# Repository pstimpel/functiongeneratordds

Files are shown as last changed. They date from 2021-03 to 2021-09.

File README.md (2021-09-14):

# A function generator based in DDS, the AD9833

IMAGE ALT TEXT HERE (https://www.youtube.com/watch?v=zaaheF0XjLw)

## Core features

- +/- 10V 
- linear power supply, builtin
- Sweep function
- Random function
- Update OTA feature
- MQTT status and settings

## Credits

The whole stuff is based on the work by Youtuber GreatScott, whos instructions you can find here: https://www.instructables.com/DIY-FunctionWaveform-Generator/

Voice in Video by https://www.text2speech.org/

## BOM
### power circuit

- Transformer 230V to 2x 15V
- 4 diodes 1n4007
- 2 2200uF caps, 35V
- 2 330uF caps, 35V
- C14 socket with fuse and switch
- some wires to connect C14 with transformer
- perfboard to mount the power circuit onto

### logic curciut

- 10u Capacitor
- 0.33u Capacitor
- 0.33u Capacitor
- 2.2u Capacitor
- 22u Capacitor
- 0.1u Capacitor
- 0.1u Capacitor
- 1u Capacitor
- 4x 100n Capacitor_SMD:C_0805
- LED 5mm
- Fuse 2A PTC
- 3x Screw Terminal Block
- GY9833 / AD9833 breakout board 3.3V
- 270 Ohms Resistor SMD: 0805
- 2x 100 Ohms Resistor THT 0.25W 5% or better
- 8-pin IC socket
- TL072 OpAmp
- 10k Trim Poti
- 10k Poti
- 50k Poti 
- AMS1117-3.3
- L7805
- L7812
- L7912
- ESP32 30 pin devboard
- Rotary Encoder
- OLED 0.96" display
- pinheaders male and female, dupont wires, stuff to wire power circuit and logic circuit together
- optional: MCP100-300D Voltage supervisor

### Case

- printed STLs from folder
- 10 screws M3x20 or similar
- 3 screws M3x12 or similar
- 1 screw M3x16 or similar
- 4 screws M4x20 or similar, 4 nuts of the same size

## How to build the case

Mount Back, bottom, front and topA to left, using M3x20 screws. Mount topB to topA by using M3x20 screws. Mount right to this whole assembly using M3x20 screws. Basically, this is the case for our Function Generator.

The lever is held to the front by an M3x16 screw, and secures the OLED.

## Logic PCB

I was creating a single sided PCB, so everyone with equipment should be able to create the PCB as well. However, I do not recommend using my board design. I had some parts laying around, and was recycling them by mixing SMD and THT with no bad feelings. 

## Improvements

2021-09-14 

- Added missing OpAmp
- replaced TL071 by TL072 for output buffering
- added 2 100 Ohms resistors in parallel to output for 50 Ohms Output
- added updated circuit and gerber stuff to repo 

## License

https://creativecommons.org/licenses/by-nc-sa/4.0/

Most obvious limits of this license:

- You are not allowed to use this stuff for commercial purposes
- You can download, reupload and change the stuff, but have to release it under the same license again
- You have the mention the origin, like "Original by Peter Stimpel, https://github.com/pstimpel/functiongeneratordds"

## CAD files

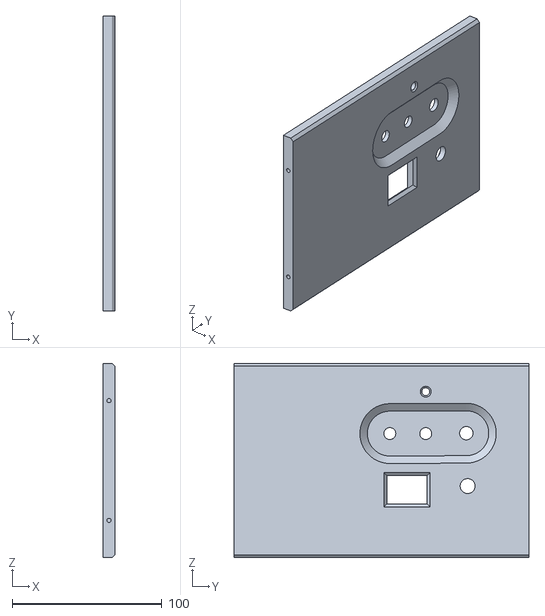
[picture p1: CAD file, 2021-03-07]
stl/front.stl
8.00 x 197.2 x 130.0

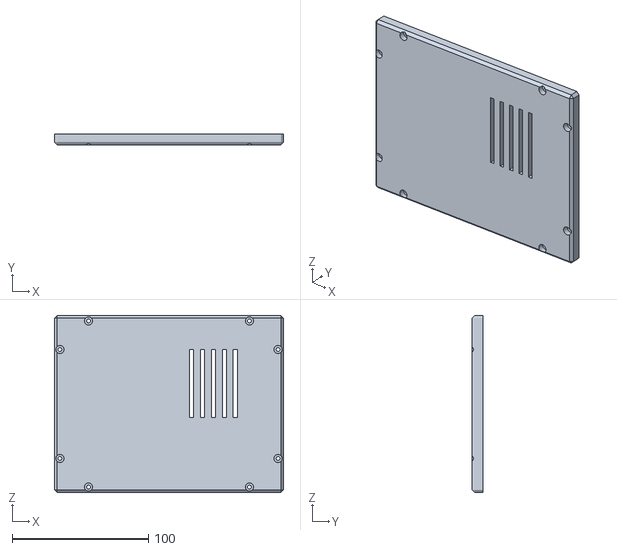
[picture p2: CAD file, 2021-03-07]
stl/left.stl
168.2 x 8.00 x 130.0

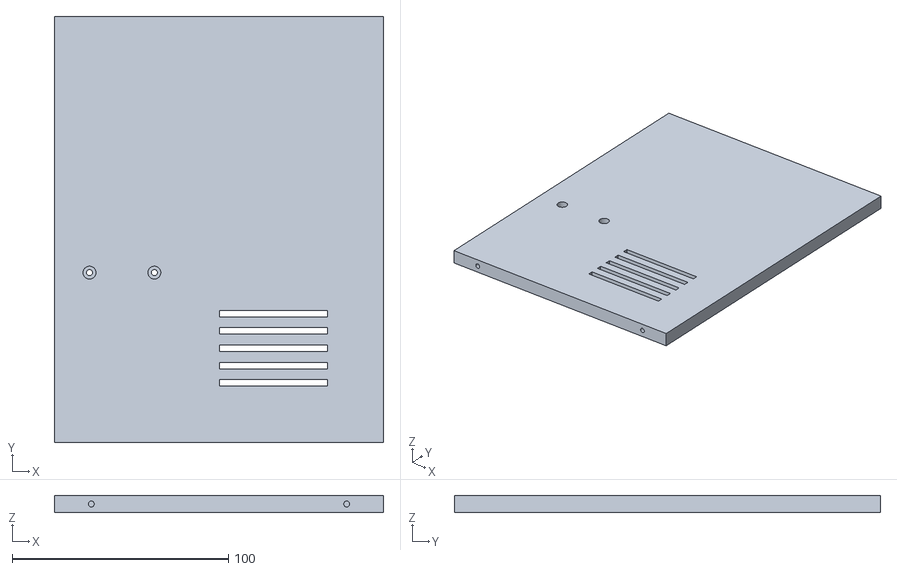
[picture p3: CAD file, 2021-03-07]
stl/topa.stl
152.2 x 197.2 x 8.00

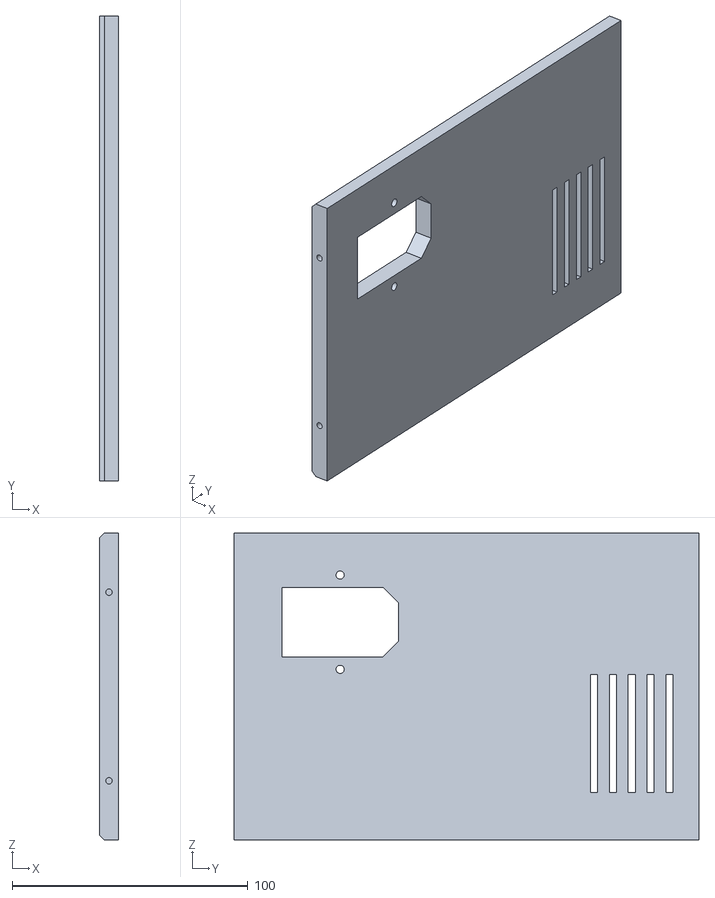
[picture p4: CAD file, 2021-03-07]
stl/back.stl
8.00 x 197.2 x 130.0

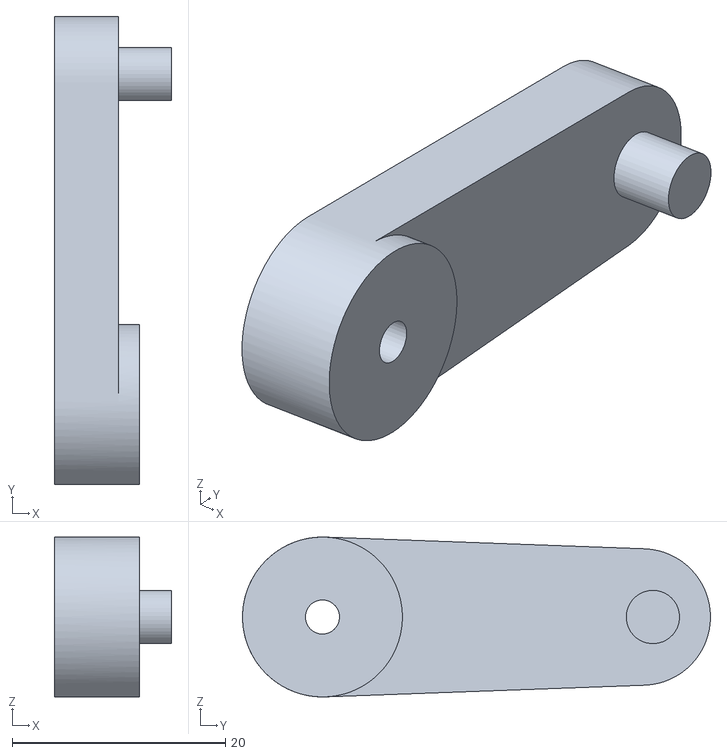
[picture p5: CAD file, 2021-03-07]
stl/lever.stl
11.0 x 43.9 x 15.0

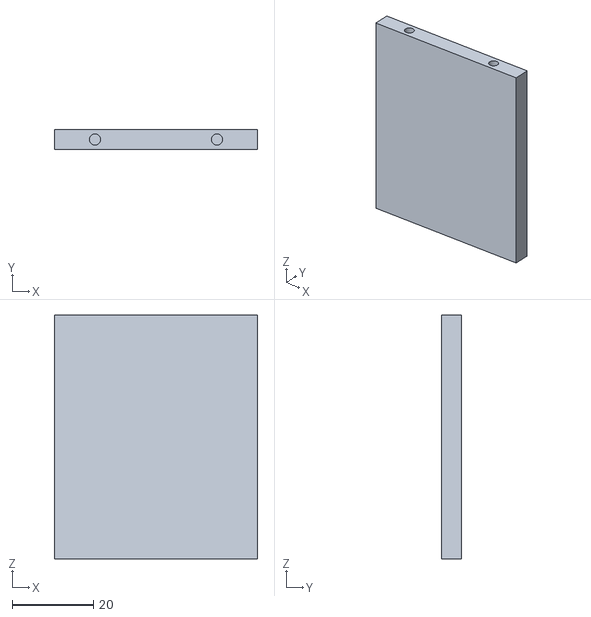
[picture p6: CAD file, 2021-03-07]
stl/topb.stl
50.0 x 5.00 x 60.0

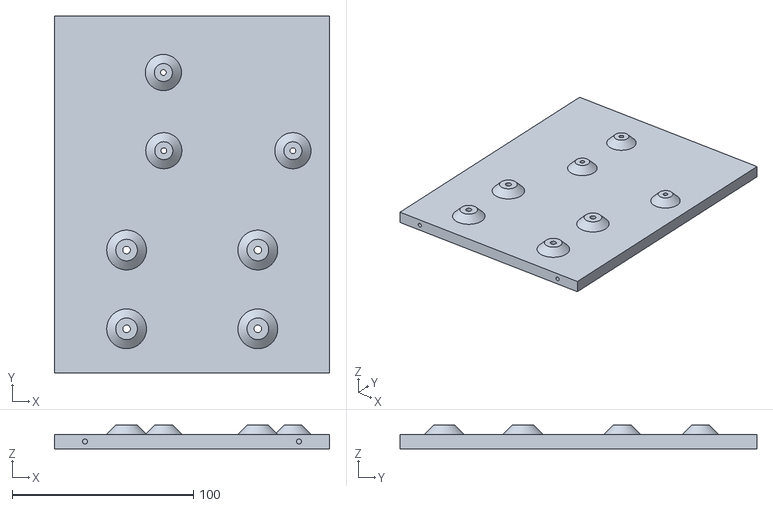
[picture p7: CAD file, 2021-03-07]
stl/bottom.stl
152.2 x 197.2 x 13.0

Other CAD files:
stl/right.stl

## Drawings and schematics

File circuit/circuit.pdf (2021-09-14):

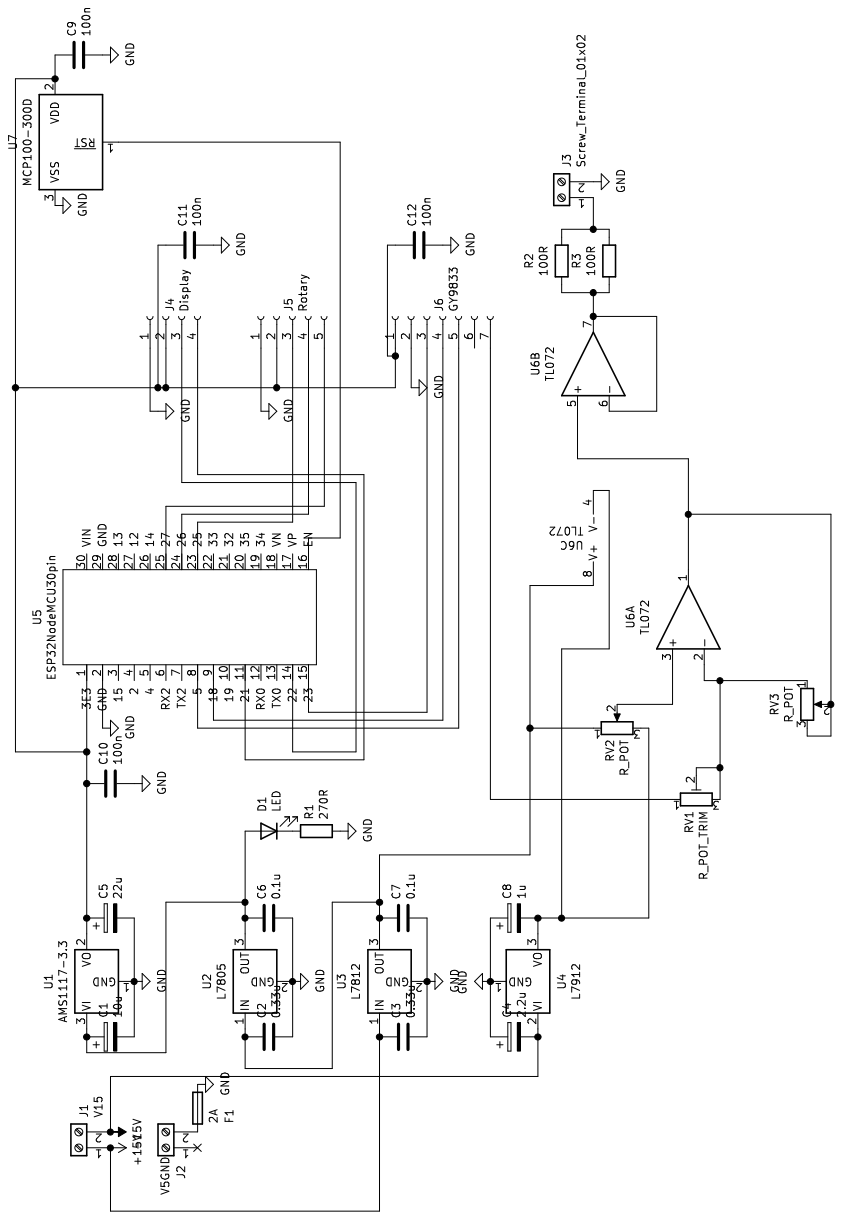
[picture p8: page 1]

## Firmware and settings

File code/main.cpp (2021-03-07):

#include <Arduino.h>
#include <MD_AD9833.h>
#include <SPI.h>
#include <ESP32Encoder.h>
#include <U8g2lib.h>
#include <Wire.h>
#include <WiFi.h>
#include <esp_wifi.h>
#include <PubSubClient.h>
#include <ArduinoJson.h>
#include <ESPmDNS.h>
#include <WiFiUdp.h>
#include <ArduinoOTA.h>
#include "time.h"

const char *versioninfo = "1.0.0-ota-1";

#define MQTT_VERSION MQTT_VERSION_3_1_1

#define DATA 23 ///< SPI Data pin number
#define CLK 18	///< SPI Clock pin number
#define FSYNC 5 ///< SPI Load pin number (FSYNC in AD9833 usage)

#define OLED_ADDR 0x3c
#define OLED_SDA 21
#define OLED_SCL 22
#define OLED_RST 16

#define ROTARY_ENCODER_A_PIN 27
#define ROTARY_ENCODER_B_PIN 26
#define ROTARY_ENCODER_BUTTON_PIN 25

#define uS_TO_S_FACTOR 1000000 /* Conversion factor for micro seconds to seconds */
#define TIME_TO_SLEEP 5        /* Time ESP32 will go to sleep (in seconds) */


U8G2_SSD1306_128X64_NONAME_F_HW_I2C u8g2(U8G2_R0, /* reset=*/OLED_RST, /* clock=*/OLED_SCL, /* data=*/OLED_SDA); // ESP32 Thing, HW I2C with pin remapping

//MD_AD9833 AD(FSYNC); // Hardware SPI
MD_AD9833 AD(DATA, CLK, FSYNC);
ESP32Encoder encoder;

volatile bool isclicked = false;
volatile boolean button = false;

const char *sensorname = "functiongeneratordds";

const char mqtt_switch_topic_command[] = "home/sensor/functiongeneratordds/out/switch";
const char mqtt_status_topic_status[] = "home/sensor/functiongeneratordds/status";
const char mqtt_SETTINGS_topic_status[] = "home/sensor/functiongeneratordds/settings";

const PROGMEM char *MQTT_CLIENT_ID = "functiongeneratordds__s";
const PROGMEM uint16_t MQTT_SERVER_PORT = 1883;
const PROGMEM char *MQTT_SENSOR_TOPIC = "home/sensor/functiongeneratordds/test";
const char *ssid = "YOURNETWORKNAME";
const char *password = "YOURPASSWORD";
const char *mqtt_server = "YOUR MQTT SERVERS IP ADDRESS";

const char* ntpServer = "pool.ntp.org";
const long  gmtOffset_sec = 0;
const int   daylightOffset_sec = 0;

const float frqUpper = 100000.0;
const float frqLower = 0.1;

float frqSingle = 1000.0;
float frqSweepLower = 1000.0;
float frqSweepUpper = 10000.0;
float sweepfrequencystep = 0.0;
float frq = frqSingle;

int duration = 5;
const int durationUpper = 3600;
const int durationLower = 1;

unsigned long encoder2lastToggled;
bool encoder2Paused = false;

volatile long oldencodervalue = 0;
bool encoderup = true;
long lastturndtected = millis();

int activeMain0 = 1;
int activeSingle1 = 1;
int activeSweep2 = 1;
int activeRandom3 = 1;
int frequencySelectedIndex = 0;
int activeScreen = 1;
char frequencychars[10];
int frequencycharsIndex = 0;
int frequencyScreenParentScreen = 0;
char integerchars[10];
int integercharsIndex = 0;
int integerSelectedIndex = 0;

bool doSingle = false;
bool doSweep = false;
bool doRandom = false;

volatile int errorcount=0;

WiFiClient wifiClient;
PubSubClient client(wifiClient);
MD_AD9833::mode_t desiredWaveform = MD_AD9833::MODE_SINE;

String charLocalTime()
{
    struct tm timeinfo;
    if(!getLocalTime(&timeinfo))
    {
    //Serial.println("Failed to obtain time");
    return "1970-01-01 00:00:00";
    }
    char timeStringBuff[50]; //50 chars should be enough
    strftime(timeStringBuff, sizeof(timeStringBuff), "%Y-%m-%dT%H:%M:%SZ", &timeinfo);
    //print like "const char*"
    return (String)timeStringBuff;
}

void print_wakeup_reason()
{
    esp_sleep_wakeup_cause_t wakeup_reason;

    wakeup_reason = esp_sleep_get_wakeup_cause();

    switch (wakeup_reason)
    {
    case ESP_SLEEP_WAKEUP_EXT0:
        Serial.println("Wakeup caused by external signal using RTC_IO");
        break;
    case ESP_SLEEP_WAKEUP_EXT1:
        Serial.println("Wakeup caused by external signal using RTC_CNTL");
        break;
    case ESP_SLEEP_WAKEUP_TIMER:
        Serial.println("Wakeup caused by timer");
        break;
    case ESP_SLEEP_WAKEUP_TOUCHPAD:
        Serial.println("Wakeup caused by touchpad");
        break;
    case ESP_SLEEP_WAKEUP_ULP:
        Serial.println("Wakeup caused by ULP program");
        break;
    default:
        Serial.printf("Wakeup was not caused by deep sleep: %d\n", wakeup_reason);
        break;
    }
}

void rebootBySleep() {
    esp_sleep_enable_timer_wakeup(TIME_TO_SLEEP * uS_TO_S_FACTOR);
    esp_deep_sleep_start();
}

void callback(char *topic, byte *message, unsigned int length)
{
    Serial.print("Message arrived on topic: ");
    Serial.print(topic);
    Serial.print(". Message: ");
    String messageTemp;

    for (int i = 0; i < length; i++)
    {
        Serial.print((char)message[i]);
        messageTemp += (char)message[i];
    }
    Serial.println();

    // Feel free to add more if statements to control more GPIOs with MQTT

    // If a message is received on the topic esp32/output, you check if the message is either "on" or "off".
    // Changes the output state according to the message
    if (String(topic) == String(mqtt_switch_topic_command))
    {
        Serial.print("Changing switch to ");
        if (messageTemp == "reset")
        {
            Serial.println(messageTemp);
            //do reset by going to deep sleep for 5 secs
            //syslog.logf(LOG_INFO, "Reset will be executed now");
            delayMicroseconds(2000000);
            rebootBySleep();
        }
        
    }
    
}

void reconnect()
{
    while (!client.connected())
    {
        //Serial.print("Attempting MQTT connection...");
        // Attempt to connect
        if (client.connect(sensorname))
        {

            //Serial.println("connected");
            // Subscribe
            client.subscribe(mqtt_switch_topic_command);
            Serial.print("sub ");
            Serial.println(mqtt_switch_topic_command);
            
            errorcount = 0;
        }
        else
        {
            Serial.print("mqtt failed, rc=");
            Serial.print(client.state());
            Serial.println(" try again in 5 seconds");
            // Wait 5 seconds before retrying
            delayMicroseconds(5000000);
        }
    }
}

String getDesiredWaveform()
{
	switch (desiredWaveform)
	{
	case MD_AD9833::MODE_SINE:
		return "Sine";
		break;
	case MD_AD9833::MODE_SQUARE1:
		return "Square 1";
		break;
	case MD_AD9833::MODE_SQUARE2:
		return "Square 2";
		break;
	case MD_AD9833::MODE_TRIANGLE:
		return "Triangle";
		break;
	case MD_AD9833::MODE_OFF:
		return "None";
		break;
	default:
		return "None";
	}
}


void mqttSendSettingsinfo() {
    StaticJsonDocument<1000> testDocument6;
	
	testDocument6["time"] = charLocalTime();
	
	testDocument6["waveform"]= (String)getDesiredWaveform();

	
	testDocument6["single"]["frequency"]= (float)frqSingle;
	if(doSingle) {
		testDocument6["single"]["isactive"] = (int)1;
	} else {
		testDocument6["single"]["isactive"] = (int)0;
	}
	
	
	testDocument6["sweep"]["frequency"]["lower"]= (float)frqSweepLower;
	testDocument6["sweep"]["frequency"]["upper"]= (float)frqSweepUpper;
	
	testDocument6["sweep"]["duration"]= (int)duration;
	if(doSweep) {
		testDocument6["sweep"]["isactive"] = (int)1;
	} else {
		testDocument6["sweep"]["isactive"] = (int)0;
	}
	
	
	if(doRandom) {
		testDocument6["random"]["isactive"] = (int)1;
	} else {
		testDocument6["random"]["isactive"] = (int)0;
	}
	
    char buffer6[1000];
    serializeJson(testDocument6, buffer6);
    Serial.println(buffer6);
    client.publish(mqtt_SETTINGS_topic_status, buffer6);
    yield();
}

void mqttSendStatusinfo() {
    StaticJsonDocument<1000> testDocument6;
	
	char bufferIP[20]; 
    IPAddress ip = WiFi.localIP();
    sprintf(bufferIP, "%d.%d.%d.%d", ip[0], ip[1], ip[2], ip[3]);
	testDocument6["IP"] = (String)bufferIP;
    
	testDocument6["lastSeenUTC"] = charLocalTime();
	
	testDocument6["version"] = (String)versioninfo;
    testDocument6["errorcount"] = (int)errorcount;
	
    char buffer6[1000];
    serializeJson(testDocument6, buffer6);
    Serial.println(buffer6);
    client.publish(mqtt_status_topic_status, buffer6);
    yield();

	mqttSendSettingsinfo();

	Serial.println("Sent");
}

float normalizeFrequency(float frequency)
{
	if (frequency < frqLower)
	{
		frequency = frqLower;
	}
	if (frequency > frqUpper)
	{
		frequency = frqUpper;
	}
	return frequency;
}

int normalizeDuration(int duration)
{
	if (duration < durationLower)
	{
		duration = durationLower;
	}
	if (duration > durationUpper)
	{
		duration = durationUpper;
	}
	return duration;
}

void isrclick()
{
	if (!isclicked)
	{
		if (digitalRead(ROTARY_ENCODER_BUTTON_PIN) == LOW)
		{
			button = true;
		}
	}
	else
	{
		//Serial.println("click blocked");
	}
}


void setFrequencyArrayFromFloat(float f_frq)
{
	String strfrq = (String)f_frq;
	strfrq.toCharArray(frequencychars, 9);
	frequencycharsIndex = strfrq.length();
	frequencySelectedIndex = 0;
}

void setIntegerArrayFromFloat(int integer)
{
	String strfrq = (String)integer;
	strfrq.toCharArray(integerchars, 9);
	integercharsIndex = strfrq.length();
	integerSelectedIndex = 0;
}

void iterateDesiredWaveform()
{
	switch (desiredWaveform)
	{
	case MD_AD9833::MODE_SINE:
		desiredWaveform = MD_AD9833::MODE_TRIANGLE;
		break;
	case MD_AD9833::MODE_TRIANGLE:
		desiredWaveform = MD_AD9833::MODE_SQUARE1;
		break;
	case MD_AD9833::MODE_SQUARE1:
		desiredWaveform = MD_AD9833::MODE_SQUARE2;
		break;
	case MD_AD9833::MODE_SQUARE2:
		desiredWaveform = MD_AD9833::MODE_OFF;
		break;
	case MD_AD9833::MODE_OFF:
		desiredWaveform = MD_AD9833::MODE_SINE;
		break;
	}
}

void switchWaveform(MD_AD9833::mode_t t_desiredWaveform)
{
	AD.reset();
	AD.setActivePhase(AD.CHAN_0);
	AD.setActiveFrequency(AD.CHAN_0);
	bool res = AD.setMode(t_desiredWaveform);
	//Serial.println(res);
	//Serial.println(t_desiredWaveform);
}

void drawStatusscreen(String header, String line1, String line2)
{
	u8g2.clearBuffer();
	u8g2.setFont(u8g2_font_unifont_tr);
	u8g2.drawStr(1, 14, header.c_str());
	u8g2.drawStr(1, 30, line1.c_str());
	u8g2.drawStr(1, 46, line2.c_str());

	u8g2.drawStr(50, 62, "back");
	u8g2.drawLine(50, 63, 80, 63);

	u8g2.sendBuffer();
}

void drawFrequencyInput(String header)
{
	u8g2.clearBuffer();
	u8g2.setFont(u8g2_font_unifont_tr);
	u8g2.drawStr(1, 14, header.c_str());
	u8g2.drawStr(13, 30, frequencychars);

	for (int i = 0; i < 10; i++)
	{
		u8g2.drawStr(i * 10, 46, ((String)i).c_str());
		if (frequencySelectedIndex == i)
		{
			u8g2.drawLine(i * 10, 47, i * 10 + 8, 47);
		}
	}

	u8g2.drawStr(100, 46, ".");
	if (frequencySelectedIndex == 10)
	{
		u8g2.drawLine(100, 47, 100 + 8, 47);
	}

	u8g2.drawStr(0, 62, "del");
	if (frequencySelectedIndex == 11)
	{
		u8g2.drawLine(0, 63, 23, 63);
	}

	u8g2.drawStr(30, 62, "ok");
	if (frequencySelectedIndex == 12)
	{
		u8g2.drawLine(30, 63, 45, 63);
	}

	u8g2.sendBuffer();
}

void drawIntegerInput(String header)
{
	u8g2.clearBuffer();
	u8g2.setFont(u8g2_font_unifont_tr);
	u8g2.drawStr(1, 14, header.c_str());
	u8g2.drawStr(13, 30, integerchars);

	for (int i = 0; i < 10; i++)
	{
		u8g2.drawStr(i * 10, 46, ((String)i).c_str());
		if (integerSelectedIndex == i)
		{
			u8g2.drawLine(i * 10, 47, i * 10 + 8, 47);
		}
	}

	u8g2.drawStr(0, 62, "del");
	if (integerSelectedIndex == 10)
	{
		u8g2.drawLine(0, 63, 23, 63);
	}

	u8g2.drawStr(30, 62, "ok");
	if (integerSelectedIndex == 11)
	{
		u8g2.drawLine(30, 63, 45, 63);
	}

	u8g2.sendBuffer();
}

void drawMenu(String header, String line1, String line2, String line3, int activeLine, bool hasScreenAbove, bool hasScreenBelow)
{
	u8g2.clearBuffer();
	u8g2.setFont(u8g2_font_unifont_tr);
	u8g2.drawStr(1, 14, header.c_str());
	u8g2.drawStr(13, 30, line1.c_str());
	u8g2.drawStr(13, 46, line2.c_str());
	u8g2.drawStr(13, 62, line3.c_str());
	switch (activeLine)
	{
	case 1:
		u8g2.drawStr(0, 30, "*");
		break;
	case 2:
		u8g2.drawStr(0, 46, "*");
		break;
	case 3:
		u8g2.drawStr(0, 62, "*");
		break;
	}

	if (hasScreenAbove)
	{
		u8g2.setFont(u8g2_font_unifont_t_symbols);
		u8g2.drawGlyph(118, 30, 0x2191); //arrow up
		u8g2.setFont(u8g2_font_unifont_tr);
	}
	if (hasScreenBelow)
	{
		u8g2.setFont(u8g2_font_unifont_t_symbols);
		u8g2.drawGlyph(118, 62, 0x2193); //arrow down
		u8g2.setFont(u8g2_font_unifont_tr);
	}
	u8g2.sendBuffer();
}

void screenMain0()
{
	activeScreen = 0;
	drawMenu("Waveformer", "Single", "Sweep", "Random", activeMain0, false, false);
}

void screenSingle1()
{
	activeScreen = 1;
	int selectedItem = activeSingle1;
	switch (activeSingle1)
	{
	case 1:
	case 2:
		selectedItem = activeSingle1;
		drawMenu("Waveformer SNG", (String)frqSingle, getDesiredWaveform(), "Start", selectedItem, false, true);
		break;
	case 3:
	case 4:
		selectedItem = activeSingle1 - 1;
		drawMenu("Waveformer SNG", getDesiredWaveform(), "Start", "back", selectedItem, true, false);
		break;
	}
}
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
void loop()
{

	if (!client.connected())
    {
        reconnect();
        errorcount++;
    }
    client.loop();

    ArduinoOTA.handle();

	bool refreshDisplay = false;
	bool encoderturndetected = false;
	long encodercount = encoder.getCount();
	if (encodercount != oldencodervalue)
	{
		if ((millis() - lastturndtected) > 400)
			{
			lastturndtected = millis();
				
			if (encodercount > oldencodervalue)
			{
				encoderup = true;
			}
			else
			{
				encoderup = false;
			}

			encoderturndetected = true;
		}
		oldencodervalue = encodercount;
	}
	
	if (encoderturndetected)
	{
		if (encoderup)
		{
			switch (activeScreen)
			{
			case 0:
				activeMain0++;
				if (activeMain0 > 3)
				{
					activeMain0 = 1;
				}
				break;
			case 1:
				activeSingle1++;
				if (activeSingle1 > 4)
				{
					activeSingle1 = 1;
				}
				break;
			case 2:
				activeSweep2++;
				if (activeSweep2 > 6)
				{
					activeSweep2 = 1;
				}
				break;
			case 3:
				activeRandom3++;
				if (activeRandom3 > 3)
				{
					activeRandom3 = 1;
				}
				break;
			case 4:
				frequencySelectedIndex++;
				if (frequencySelectedIndex > 12)
				{
					frequencySelectedIndex = 0;
				}
				break;
			case 6:
				integerSelectedIndex++;
				if (integerSelectedIndex > 11)
				{
					integerSelectedIndex = 0;
				}
				break;
			}
		}
		else
		{
			switch (activeScreen)
			{
			case 0:
				activeMain0--;
				if (activeMain0 < 1)
				{
					activeMain0 = 3;
				}
				break;
			case 1:
				activeSingle1--;
				if (activeSingle1 < 1)
				{
					activeSingle1 = 4;
				}
				break;
			case 2:
				activeSweep2--;
				if (activeSweep2 < 1)
				{
					activeSweep2 = 6;
				}
				break;
			case 3:
				activeRandom3--;
				if (activeRandom3 < 1)
				{
					activeRandom3 = 3;
				}
				break;
			case 4:
				frequencySelectedIndex--;
				if (frequencySelectedIndex < 0)
				{
					frequencySelectedIndex = 12;
				}
				break;
			case 6:
				integerSelectedIndex--;
				if (integerSelectedIndex < 0)
				{
					integerSelectedIndex = 11;
				}
				break;
			}
		}

		refreshDisplay = true;
	}

	if (button)
	{
		isclicked = true;
		button = false;
		String strfrq;
		switch (activeScreen)
		{
		case 0: //Main
			switch (activeMain0)
			{
			case 1:
				activeSingle1 = 1;
				activeScreen = 1;
				break;
			case 2:
				activeSweep2 = 1;
				activeScreen = 2;
				break;
			case 3:
				activeRandom3 = 1;
				activeScreen = 3;
				break;
			}

			break;
		case 1: //Single

			switch (activeSingle1)
			{
			case 1:
				activeScreen = 4;
				setFrequencyArrayFromFloat(frqSingle);
				frequencyScreenParentScreen = 1;
				break;
			case 2:
				iterateDesiredWaveform();
				break;
			case 3:
				//start the havoc
				activeScreen = 5;
				setFrequencyArrayFromFloat(frqSingle);
				frequencyScreenParentScreen = 1;
				frq=frqSingle;
				AD.setFrequency(MD_AD9833::CHAN_0, frq);
				switchWaveform(desiredWaveform);
				doSingle=true;
				mqttSendStatusinfo();
				break;
			case 4:
				activeMain0 = 1;
				activeScreen = 0;
				switchWaveform(MD_AD9833::MODE_OFF);
				AD.reset();
				doSingle=false;
				mqttSendStatusinfo();
				break;
			}

			break;
		case 2: //Sweep

			switch (activeSweep2)
			{
			case 1: //set lower frequency
				activeScreen = 4;
				setFrequencyArrayFromFloat(frqSweepLower);
				frequencyScreenParentScreen = 2;
				break;
			case 2: //set upper frequency
				activeScreen = 4;
				setFrequencyArrayFromFloat(frqSweepUpper);
				frequencyScreenParentScreen = 3;
				break;
			case 3: //set frequency form
				iterateDesiredWaveform();

				break;
			case 4: //duration
				activeScreen = 6;
				setIntegerArrayFromFloat(duration);
				frequencyScreenParentScreen = 4;

				break;
			case 5: //start sweep
				if (frqSweepLower >= frqLower && frqSweepUpper <= frqUpper && duration >= durationLower && duration <= durationUpper)
				{
					float sweepsteps = (float)duration * 8.0;
					if (frqSweepUpper != frqSweepLower)
					{
						sweepfrequencystep = (frqSweepUpper - frqSweepLower) / sweepsteps;
						//Serial.println(sweepfrequencystep);
					}
					else
					{
						sweepfrequencystep = 0.0;
					}
					doSweep = true;
					frq = frqSweepLower;
					frequencyScreenParentScreen = 4;
					AD.setFrequency(MD_AD9833::CHAN_0, frq);
					switchWaveform(desiredWaveform);

					mqttSendStatusinfo();
				}

				break;
			case 6: //go back
				activeMain0 = 2;
				activeScreen = 0;
				switchWaveform(MD_AD9833::MODE_OFF);
				AD.reset();
				doSweep=false;
				mqttSendStatusinfo();
				break;
			}

			break;
		case 3: //random

			switch (activeRandom3)
			{
			case 1:
				iterateDesiredWaveform();
				break;
			case 2:
				//start the havoc
				activeScreen = 5;
				frequencyScreenParentScreen = 5;
				frq = (float)random((long)1, (long)frqUpper);
				setFrequencyArrayFromFloat(frq);
				AD.setFrequency(MD_AD9833::CHAN_0, frq);
				switchWaveform(desiredWaveform);
				doRandom = true;
				mqttSendStatusinfo();
				break;
			case 3:
				activeMain0 = 3;
				activeScreen = 0;
				switchWaveform(MD_AD9833::MODE_OFF);
				AD.reset();
				doRandom=false;
				mqttSendStatusinfo();
				break;
			}

			break;
		case 4: //Frequency Set
			switch (frequencySelectedIndex)
			{
			case 0:
			case 1:
			case 2:
			case 3:
			case 4:
			case 5:
			case 6:
			case 7:
			case 8:
			case 9:
				if (frequencycharsIndex < 10)
				{
					frequencychars[frequencycharsIndex] = (48 + frequencySelectedIndex);
					frequencycharsIndex++;
				}

				break;
			case 10:
				char *pch;
				pch = strchr(frequencychars, '.');
				if (pch == NULL)
				{
					if (frequencycharsIndex < 10)
					{
						frequencychars[frequencycharsIndex] = '.';
						frequencycharsIndex++;
					}
				}
				break;
			case 11:
				if (frequencycharsIndex > 0)
				{
					frequencychars[frequencycharsIndex - 1] = 0;
					frequencycharsIndex--;
				}
				break;
			case 12:
				switch (frequencyScreenParentScreen)
				{
				case 1:
					frqSingle = ((String)frequencychars).toFloat();
					frqSingle = normalizeFrequency(frqSingle);
					activeScreen = 1;
					activeSingle1 = 1;
					break;
				case 2:
					frqSweepLower = ((String)frequencychars).toFloat();
					frqSweepLower = normalizeFrequency(frqSweepLower);
					activeScreen = 2;
					activeSweep2 = 1;
					break;
				case 3:
					frqSweepUpper = ((String)frequencychars).toFloat();
					frqSweepUpper = normalizeFrequency(frqSweepUpper);
					activeScreen = 2;
					activeSweep2 = 2;
					break;
				}
				break;
			}
			break;
		case 5: //status
			switch (frequencyScreenParentScreen)
			{
			case 1:
				switchWaveform(MD_AD9833::MODE_OFF);
				frq=frqSingle;
				AD.reset();
				activeScreen = 1;
				activeSingle1 = 3;
				doSingle=false;
				mqttSendStatusinfo();
				//Serial.println("off on leave");
				break;
			case 4:
				doSweep = false;
				frq = frqSweepLower;
				switchWaveform(MD_AD9833::MODE_OFF);
				AD.reset();
				activeScreen = 2;
				activeSweep2 = 5;
				mqttSendStatusinfo();
				//Serial.println("off on leave");
				break;
			case 5:
				doRandom = false;
				frq = frqLower;
				switchWaveform(MD_AD9833::MODE_OFF);
				AD.reset();
				activeScreen = 3;
				activeRandom3 = 2;
				mqttSendStatusinfo();
				//Serial.println("off on leave");
				break;
			}
			break;
		case 6: //integer Set
			switch (integerSelectedIndex)
			{
			case 0:
			case 1:
			case 2:
			case 3:
			case 4:
			case 5:
			case 6:
			case 7:
			case 8:
			case 9:
				if (integercharsIndex < 10)
				{
					integerchars[integercharsIndex] = (48 + integerSelectedIndex);
					integercharsIndex++;
				}

				break;
			case 10:
				if (integercharsIndex > 0)
				{
					integerchars[integercharsIndex - 1] = 0;
					integercharsIndex--;
				}
				break;
			case 11:
				switch (frequencyScreenParentScreen)
				{
				case 4:
					duration = ((String)integerchars).toInt();
					duration = normalizeDuration(duration);
					activeScreen = 2;
					activeSweep2 = 4;
					break;
				}
				break;
			}
			break;
		}

		delayMicroseconds(500000);
		isclicked = false;
		refreshDisplay = true;
	}

	if (refreshDisplay)
	{
		switch (activeScreen)
		{
		case 0:
			screenMain0();
			break;
		case 1:
			screenSingle1();
			break;
		case 2:
			screenSweep2();
			break;
		case 3:
			screenRandom3();
			break;
		case 4:
			screenFrequencySelect4();
			break;
		case 5:
			screenStatus5();
			break;
		case 6:
			screenIntegerSelect6();
			break;
		}
	}

	if (doRandom)
	{
		frq = (float)random((long)1, (long)frqUpper);
		/*
		Serial.print(frq);
		Serial.print("");
		Serial.println("");
		*/
		AD.setFrequency(MD_AD9833::CHAN_0, frq);
		activeScreen = 5;
		frequencyScreenParentScreen = 5;
		setFrequencyArrayFromFloat(frq);
		screenStatus5();
		//delayMicroseconds(200000);
	}

	if (doSweep)
	{
		frq = frq + sweepfrequencystep;
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

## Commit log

2021-03-07 V1 Readme, BOM
2021-03-07 Finalize Readme, add stuff to different folders
    [FunctionGeneratorDDS-B_Cu.gbr, FunctionGeneratorDDS-B_Mask.gbr, FunctionGeneratorDDS-B_Paste.gbr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]
2021-09-14 Added missing OpAmp Replaced TL071 by TL072 for output buffering Added 2 100 Ohms resistors in parallel to output for 50 Ohms Output Added updated circuit and gerber stuff to repo
    [FunctionGeneratorDDS-B_Cu.gbr, FunctionGeneratorDDS-B_Mask.gbr, FunctionGeneratorDDS-B_Paste.gbr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]
